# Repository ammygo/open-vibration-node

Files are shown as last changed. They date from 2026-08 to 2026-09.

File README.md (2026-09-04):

# Open Vibration Node

An open hardware and open firmware vibration sensing node for industrial condition
monitoring — analysing vibration **on the device** and reporting results over LoRaWAN to a
gateway you run yourself, with no mandatory cloud service.

> **Status: sensor board verified, radio path not yet exercised.** The second-generation
> sensor board has been manufactured and verified on the bench — the sensor identifies
> correctly, gravity and impact-response tests pass, and the noise floor sits at ~18 mg RMS
> across the full 6.3 kHz bandwidth on a bench ([measurements](docs/measurements.md)). The RAK3112 module has so far served only as the
> host MCU for those tests; the SX1262 radio has not yet been brought up. Mechanical
> integration and the signal-processing firmware are the current work.

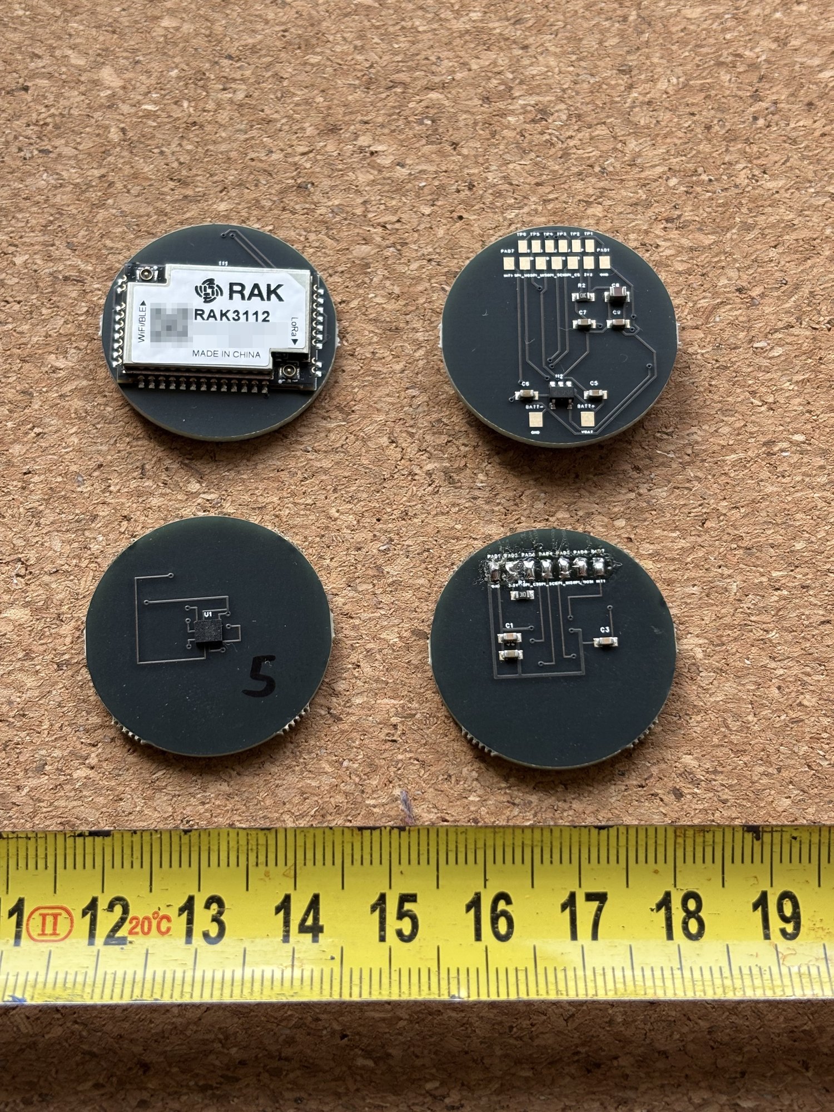
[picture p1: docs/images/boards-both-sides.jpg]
Both boards, both sides, with a ruler for scale


*The two 28 mm boards that make up a node — sensor board and radio board, both sides.
More photographs: [docs/images](docs/images/).*

## Why this project exists

Predictive maintenance works: measuring vibration on motors, bearings, pumps and fans
reveals developing faults weeks or months before they cause a breakdown. The techniques
are well documented in engineering literature, and the sensors cost a few euros.

Access to them is not open, though. Commercial condition-monitoring systems are closed
end to end — proprietary sensors, proprietary gateways, and a vendor cloud that must stay
reachable and paid for, or the equipment stops being monitored. Prices start in the
hundreds of euros per measurement point, which puts continuous monitoring out of reach for
small manufacturers, municipal utilities, water pumping stations and building services —
exactly the operators who can least afford an unplanned failure.

Open vibration-monitoring projects do exist. The ones I have found stop at a development
board on a desk, depend on a vendor cloud, or use accelerometers limited to a few hundred
hertz — which rules out the 1–6 kHz region where bearing faults first appear. What is
missing is a node that combines the bandwidth needed for real diagnostics with local-first
operation and documentation good enough to rebuild it. This project aims to be that node.

## How this compares with existing work

| Approach | Usable bandwidth | Power / connectivity | Openness |
|---|---|---|---|
| Commercial condition-monitoring systems | Full (piezo-based) | Battery or wired; vendor cloud mandatory | Closed end to end; per-point pricing plus subscription |
| Open builds on consumer MEMS (ADXL345 / LIS3DH class) | ~200–800 Hz | Battery; various | Open, but physically blind to the 1–6 kHz bearing-fault region |
| Wired piezo + DAQ setups | Full | Mains power and cabling per point | Mixed; cabling dominates per-point cost |
| **This project** | **DC–6.3 kHz (IIS3DWB)** | **Battery + LoRa; local-first, no mandatory cloud** | **Open: hardware, firmware, docs, production files** |

Open lab-instrument projects — open microscopes, open test equipment — have already shown
that *laboratory-grade but open and rebuildable* is a workable model. This project applies
that model to industrial vibration monitoring.

## Design goals

These are the goals the design is being built towards, not a description of what already
works — see the status above.

- **Analysis on the device.** FFT and envelope processing run on the node's MCU. Only
  results leave the device — a compact payload of dominant frequencies, amplitudes, RMS
  and temperature (target: under 24 bytes), not raw waveforms. This is what makes
  battery-powered operation over a low-bandwidth radio possible at all.
- **Local-first.** LoRaWAN with a self-hosted [ChirpStack](https://www.chirpstack.io/)
  network server: the reference gateway is a Raspberry Pi 5 with an SX1302 eight-channel
  concentrator, and everything from radio to database runs on hardware the operator owns.
  No account, no vendor cloud, no remote kill switch. Cloud services are optional, never
  required.
- **Auditable and reproducible.** Schematics, bill of materials, firmware source and
  enclosure models under free licences, with build documentation detailed enough to
  reproduce a working node.
- **Long field life.** Multi-year operation on a primary lithium cell. Sealed enclosure
  for industrial and outdoor use.
- **Secure by design.** Per-device keys, signed firmware updates and a published software
  bill of materials, so that nodes remain maintainable under the EU Cyber Resilience Act
  rather than becoming unsupported hardware.

## Hardware

| Block | Part | Key figures |
|---|---|---|
| Accelerometer | STMicroelectronics **IIS3DWB** | DC–6.3 kHz flat bandwidth, 26.667 kHz ODR, 75 µg/√Hz noise density, ±2/4/8/16 g, SPI, −40…+105 °C, integrated temperature sensor |
| MCU + radio | RAK Wireless **RAK3112** | ESP32-S3 + Semtech SX1262 in one certified module (LoRa 868 MHz, WiFi, BLE), 23×15 mm |
| Power | Diodes **AP2112K-3.3** LDO | 600 mA, SOT-23-5 (LCSC C51118) |

### Why these parts

**IIS3DWB.** Bearing and mechanical fault signatures live in the 1–6 kHz region, while
ordinary MEMS accelerometers (ADXL345, LIS3DH and similar) are limited to 200–800 Hz —
they physically cannot see what matters. The IIS3DWB gives a flat 6.3 kHz bandwidth at
75 µg/√Hz noise in a single 2.5 × 3.0 mm package, so diagnostics that previously required
a piezoelectric accelerometer with an external conditioner now fit in a 28 mm node running
from a battery.

**RAK3112.** The ESP32-S3 has enough compute to run the FFT locally, which is the whole
premise of the design: the node transmits a spectral summary rather than raw waveforms,
which is what makes both the battery budget and the LoRa duty cycle work. Combining it
with the SX1262 in one certified module means a single component instead of MCU plus radio
plus RF matching, and no antenna network to design. The trade-off is board area in
exchange for reproducibility and a simpler certification path — a deliberate choice for a
project that others are meant to be able to rebuild.

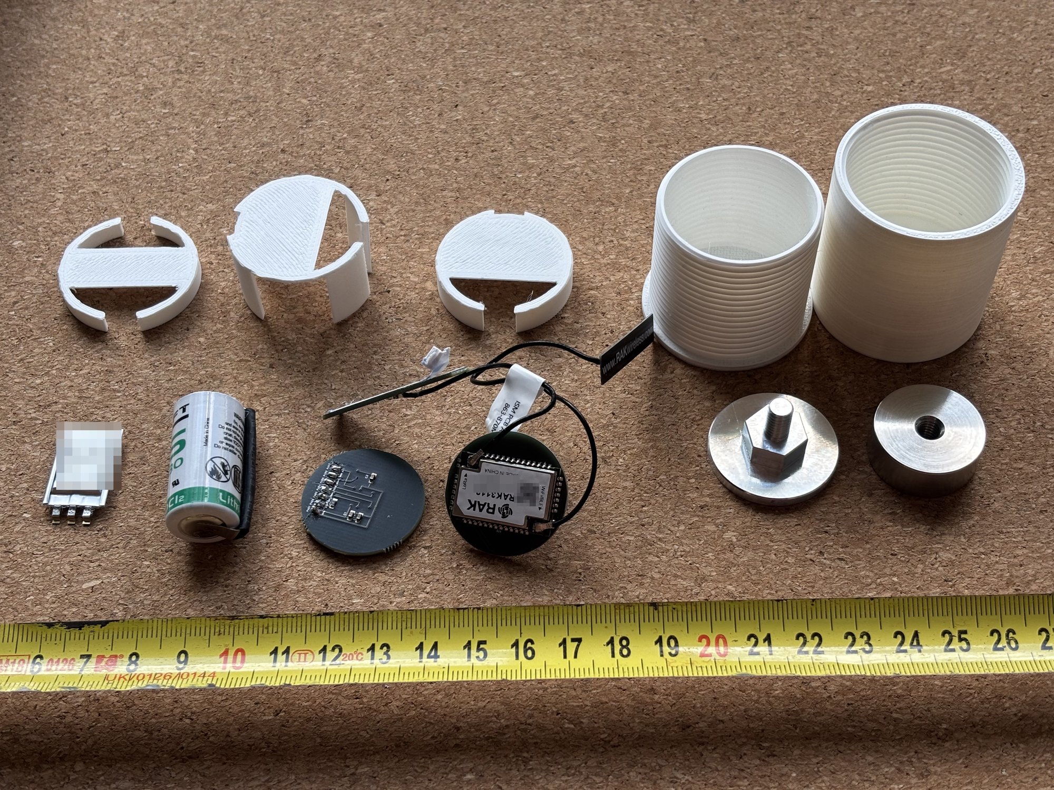
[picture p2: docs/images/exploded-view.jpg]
Every part of a node laid out


*Everything that goes into one node: the two boards, primary cell, energy buffer,
antennas, printed housing and the aluminium mounting pad.*

### Board architecture

Two 28 mm round boards with the battery between them, joined by seven wires:

- **Sensor board** — IIS3DWB on the bottom layer, facing the measured surface, with
  decoupling capacitors and a CS pull-up.
- **Radio board** — RAK3112 on the top layer (antenna facing away from metal), LDO and
  power components underneath.

Inter-board signals: `GND`, `3V3`, `SPI_CS`, `SPI_SCK`, `SPI_MISO`, `SPI_MOSI`, `INT1`.
Pad order is identical on both boards, so the wires run straight across without crossing.

Placing the accelerometer on the bottom layer is deliberate — it shortens the mechanical
path between the measured surface and the sensing element, which matters far more for
signal fidelity than any amount of filtering afterwards.

### Two data paths

A node normally sends only a spectral summary — a payload of a couple of dozen bytes,
which is what makes years of battery life on a low-bandwidth radio possible at all. That
summary is enough to trend a machine's condition, but not to investigate a fault in detail.

So the node keeps a second path. The RAK3112 carries 8 MB of PSRAM, enough to hold about
50 seconds of the full 26.667 kHz three-axis stream. When something in the trend needs
looking at, an engineer standing next to the machine can trigger a capture and pull the
raw recording off over WiFi, straight to a laptop — no cloud and no gateway involved.
This path works on the bench as of September 2026: a downlink command makes the node record
32768 samples per axis (1.23 s — the PSRAM allows about 50 s; 1.23 s is the current capture
length) from the sensor FIFO into PSRAM and post them over WiFi to the collector (the local
server described above; a laptop also works), which it locates by mDNS.

This is deliberately **on demand** rather than continuous: streaming raw data would end the
battery budget within days. Routine monitoring stays cheap; full detail is available when
it is actually needed.

## Repository layout

| Path | Contents |
|---|---|
| `firmware/tests/` | Bench verification sketches — sensor identification and acquisition |
| `docs/` | Measurements, payload specification draft, build notes |
| `enclosure/` | Mounting pad and housing — CAD sources with open-format exports |
| `tools/` | Design-check utilities: a mirrored-footprint checker and the velocity-RMS filter validation script |
| `hardware/` | KiCad boards plus gerbers, BOM and pick-and-place files for both boards |

## Licences

- Firmware and software: [MIT](LICENSE)
- Hardware design files: CERN-OHL-W-2.0 (see `hardware/LICENSE.txt`)
- Documentation: CC-BY-SA-4.0

## Roadmap

Timing is indicative and assumes part-time development; with project funding it compresses.

1. ~~Sensor board validated on hardware~~ — done, August 2026 ([measurements](docs/measurements.md))
2. ~~Radio bring-up: SX1262 transmit and receive path~~ — done, September 2026: point-to-point
   LoRa link (869.525 MHz, SF7) in both directions, downlink-configurable cadence within the
   duty-cycle budget, on-demand raw capture over WiFi; velocity RMS in the ISO 10816 band
   validated ([measurements](docs/measurements.md#velocity-rms-in-the-iso-10816-band-added-2-september-2026)).
   The interim link terminates in a USB LoRa receiver on the collector (the local server
   described under *Local-first*); roadmap item 4 replaces it with the SX1302 LoRaWAN gateway
   and ChirpStack.
3. Mechanical integration: sensor coupling, sealing, field-ready housing (pad and housing
   models [published](enclosure/); sealing details in progress) — winter 2026/27
4. On-device FFT and envelope processing, LoRaWAN uplink with a versioned payload format
   ([draft specification](docs/payload-spec.md)) — spring 2027. *Interim: FFT, envelope and
   waterfall spectra are computed on the collector from FIFO captures; each packet already
   carries band-limited velocity RMS, crest factor and a sensor-health flag
   ([status](docs/payload-spec.md#bench-protocol-status-2-september-2026)).*
5. Characterisation against a reference accelerometer on a shaker — spring/summer 2027
6. Field deployment on real rotating equipment, with published measurement data — second
   half of 2027
7. Documented reproducible build — someone else assembles a node from this repository —
   late 2027

## About

Built by Laurynas Misiūnas, an electronics engineer in Klaipėda district, Lithuania, with
six years of industrial experience deploying edge AI vision systems and embedded
controllers on production lines. Developed with the support of the Klaipėda Science and
Technology Park (KMTP) innovation support programme.

Contributions, review and questions are welcome — see [CONTRIBUTING.md](CONTRIBUTING.md) or open an issue.

## Transparency: use of generative AI

Engineering decisions, architecture and project direction in this repository are made by
the author. Documentation and English-language texts are drafted with the assistance of a
large language model (Anthropic Claude) and reviewed, corrected and approved by the author
before publication. Commits with LLM-assisted content carry a `Co-Authored-By: Claude`
trailer. Details in [TRANSPARENCY.md](TRANSPARENCY.md).

No firmware, hardware design files or measurement data will be presented as project
deliverables without human authorship and verification.

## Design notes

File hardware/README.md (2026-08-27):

# Hardware

Two 28 mm round boards, joined by seven wires with the battery between them.

Licence: CERN-OHL-W-2.0 — see [LICENSE.txt](LICENSE.txt).

| Path | Board | Contents |
|---|---|---|
| `sensor-board/` | IIS3DWB accelerometer, bottom layer | KiCad board, gerbers, BOM, pick-and-place |
| `radio-board/` | RAK3112 module (ESP32-S3 + SX1262), LDO | KiCad board, gerbers, BOM, CPL, pick-and-place |

The `production/` files under each board are the sets actually sent for fabrication and
assembly — not idealised exports. Boards from these files have been manufactured and the
sensor board verified on the bench ([measurements](../docs/measurements.md)).

### What the KiCad sources are and are not

**The gerbers are the authoritative artifact** — they are what was manufactured. The KiCad
files are the design sources behind them, and on both boards they differ from the gerbers
in ways worth knowing before you rebuild:

- **Sensor board** — fully routed, but one CS track and its via sit about 0.1 mm from
  where the manufactured gerbers place them. The final clearance fix was applied in the
  export tool rather than back-annotated to KiCad. Electrically identical; regenerating
  gerbers from KiCad will not produce a byte-identical set.
- **Radio board** — carries **placement and netlist only, with no routing**. The routing
  was done in the export tool and exists solely in the gerbers. Opening this file will
  show an unrouted board; that is the actual state of the source, not a damaged file.

If you intend to modify either design, start from the gerbers for what was built and treat
the KiCad files as the placement reference.

Both boards, both sides

*Sensor board (bottom row) and radio board (top row), both sides. The accelerometer sits
on the underside of the sensor board; the RAK3112 module on the top of the radio board.*

## Inter-board wiring

`GND`, `3V3`, `SPI_CS`, `SPI_SCK`, `SPI_MISO`, `SPI_MOSI`, `INT1`.

Pad order is identical on both boards, so the wires run straight across without crossing.

## Layout constraints worth knowing

Two requirements pull against each other on a 28 mm board, and the layout is the
compromise between them:

- The accelerometer needs a **short, stiff mechanical path** to the mounting surface,
  which is why it sits on the bottom layer facing the measured surface rather than on top.
- The radio needs a **clean ground plane and antenna keep-out**, which is why the module
  sits on the top layer with the antenna facing away from the mounted metal.

Splitting these onto two boards resolves the conflict; the cost is the seven-wire harness
and the assembly step that goes with it.

## Before you reorder these boards

Run [`../tools/check_handedness.py`](../tools/README.md) against the sensor board. A
mirrored bottom-layer footprint passes design rule checking and fabricator review and
still cannot be assembled — that mistake cost three revisions here.

## Bill of materials

The BOM files carry LCSC part numbers where the boards were assembled with them, so the
component selection can be reproduced directly. Prices, suppliers and order references are
deliberately not included.

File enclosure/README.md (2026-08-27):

# Enclosure and mechanical parts

Licence: CERN-OHL-W-2.0 (same terms as `../hardware`); documentation CC-BY-SA-4.0.

| Path | Contents |
|---|---|
| `mounting-pad/` | Threaded pad coupling the sensor board to the machine surface — published |
| `housing/` | Sensor housing, revision 3 — published, sealing details in progress |

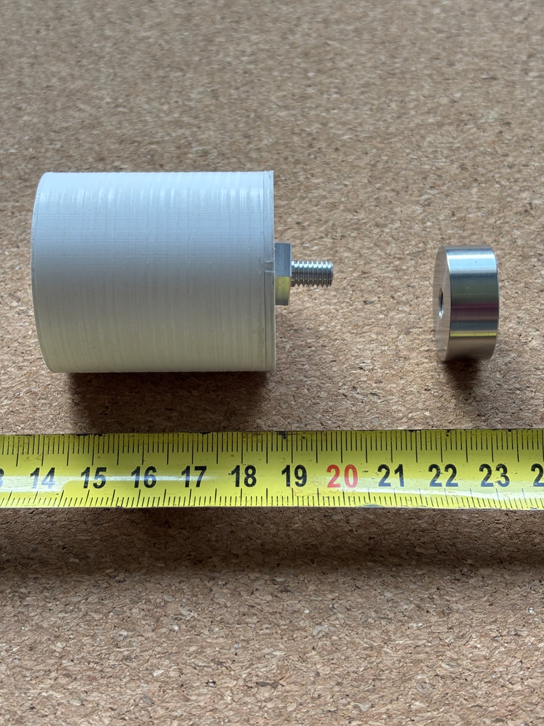
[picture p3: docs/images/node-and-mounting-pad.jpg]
Node alongside the aluminium mounting pad


*The node screws onto the pad by its M6 stud; the pad is turned into the machine housing.
Assembled views: [upright](../docs/images/assembled-node-upright.jpg),
[side](../docs/images/assembled-node-side.jpg),
[opened](../docs/images/housing-open.jpg).*

## Design notes

The enclosure has to do three things at once: transmit vibration faithfully from the
mounting surface to the sensor, keep moisture and dust out, and not shield the antenna.

Planned approach: a stiff mounting path from the pad through the board to the sensor, a
gasket groove for an EPDM or silicone O-ring cord (printed gaskets leak through layer
lines and are not used for sealing), a membrane-vented port to equalise pressure without
admitting water, and a radio-transparent section over the antenna.

Materials: current prototypes are printed in PLA, which is adequate for fit checks on the
bench and nothing more. Field units need ASA for outdoor and UV exposure, or PC/PC-FR where
surface temperatures are high; both require a heated chamber to print without warping, and
printer requirements will be documented alongside the profiles.

Threaded brass inserts are used for all fasteners; printed threads do not survive repeated
opening or vibration.

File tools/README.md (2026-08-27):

# Tools

## `check_handedness.py` — catching mirrored footprints on the bottom layer

A mirrored footprint is one of the few PCB errors that survives every normal check.
Design rule checking passes, the fabricator's review passes, the boards arrive looking
perfect — and the chip cannot be assembled correctly, because no rotation will ever bring
its pins onto the right pads. In this project that mistake killed three board revisions
before it was understood.

This script catches it before the order is placed.

### The rule, in plain language

A chip lying lands-up on a table looks exactly like the datasheet **bottom view**. Lifting
it straight up onto the underside of a board changes nothing about that arrangement.

Therefore: for a bottom-mounted part, the pad positions in world coordinates must match
the datasheet bottom view **up to a single common rotation** — 0°, 90°, 180° or 270°.
If no rotation matches, the footprint is mirrored, and no amount of rotating in the
assembly file will fix it.

Understanding this rule matters more than running the script. The script only automates
the comparison.

### What it does

Reads pad coordinates straight from the KiCad `.kicad_pcb` file, converts them into world
coordinates, and compares them against the datasheet's bottom-view land positions at each
of the four rotations, reporting the worst-case pad error for each.

### Example output

Current sensor board — correct footprint:

```
================================================================
HANDEDNESS CHECK: bottom-v5
   rotation   0 deg: max pad error = 2.9369 mm
   rotation  90 deg: max pad error = 2.0767 mm
   rotation 180 deg: max pad error = 0.0000 mm
   rotation 270 deg: max pad error = 2.0767 mm
   >>> PASS: pads = datasheet BOTTOM VIEW rotated 180 deg
   >>> chip is PLACEABLE; CPL rotation must be 180 deg
```

One rotation lands at zero error — the footprint is correct, and the assembly file must
use that same rotation. On a mirrored footprint all four rotations stay far from zero and
the script reports `FAIL: FOOTPRINT IS MIRRORED`; that is the outcome that would have
saved three board revisions here.

### Usage

```
python check_handedness.py path/to/board.kicad_pcb
```

No dependencies beyond the Python standard library.

### Adapting it to another part

Two things are specific to this project and need editing for a different design:

- `DS_BOTTOM` — the land coordinates read from the datasheet's package drawing. Replace
  with the values for your part.
- The board-origin offsets in the world-coordinate conversion (`- 150.0`, `- 100.0`) —
  set these to your board's origin.

The footprint filter currently selects `LGA-14`; change it to match your package name.

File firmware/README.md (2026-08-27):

# Firmware

Node firmware: sampling, on-device signal processing, power management and LoRaWAN uplink.

Licence: MIT — see [../LICENSE](../LICENSE).

## Contents

Bench sketches are under `tests/`. Still to come:

- `src/` — application and signal processing sources
- `drivers/` — sensor and peripheral drivers
- `docs/` — payload format specification and decoder

## Processing pipeline

```
sample burst  ──►  window  ──►  FFT + envelope  ──►  extract features  ──►  pack payload
(configurable      (Hann)      (band-limited)       (peaks, RMS, temp)     (< 24 bytes)
 rate and length)
```

The node stays asleep between measurements, wakes on schedule or on an RMS threshold,
computes locally and transmits only extracted features. Raw waveforms are never sent over
the radio — they can optionally be stored on local media for offline analysis.

## Payload

The uplink format will be documented as a versioned specification, with a reference
decoder so that any LoRaWAN network server can interpret the data without proprietary
software. Every payload carries a format version byte so that decoders and firmware can
evolve independently.

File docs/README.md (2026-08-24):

# Documentation

Build instructions, measurement methodology and test results.

Licence: CC-BY-SA-4.0.

## Planned contents

- `build/` — step-by-step assembly, from bare PCB to sealed node
- `commissioning/` — mounting guidance, orientation, sampling configuration
- `methodology/` — how measurements are taken and interpreted: baseline capture,
  temperature correction, threshold selection
- `measurements/` — published datasets from bench and field tests, with the raw data

## Why the methodology matters

A vibration reading on its own means nothing. A useful node needs a baseline for the
specific machine, grouped by temperature, and thresholds derived from that baseline rather
than from generic limits. Documenting this properly is as much of the project as the
hardware — it is the part that decides whether an operator gets early warnings or a stream
of false alarms.

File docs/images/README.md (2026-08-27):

# Photographs

Images of the hardware as built, August 2026.

| File | What it shows |
|---|---|
| `boards-both-sides.jpg` | Both boards, both sides, with a ruler for scale |
| `exploded-view.jpg` | Every part of a node laid out: boards, battery, energy buffer, antennas, housing, mounting pad |
| `assembled-node-upright.jpg` | Assembled node standing on its mounting pad |
| `assembled-node-side.jpg` | The same node from the side, showing the pad interface |
| `node-and-mounting-pad.jpg` | Node with its M6 stud alongside the aluminium pad it screws into |
| `housing-open.jpg` | Housing opened, electronics in place |
| `bench-setup.jpg` | Bench setup during acquisition testing |
| `bench-demo-output.jpg` | Serial output of the self-check demo |

## A note on what is obscured

Device identifiers on the radio module and the markings on the energy-buffer capacitor are
pixelated. Everything relevant to rebuilding the node — component choice, layout, wiring,
mechanics — is in the [hardware](../../hardware/) files.

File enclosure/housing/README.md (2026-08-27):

# Sensor housing

Enclosure for the two-board sensor stack, revision 3.

> **Work in progress.** The model is published as it stands, at the stage where the board
> stack and mounting interface are settled but sealing details are still being worked
> through. It is here so the mechanical direction can be reviewed and reused, not because
> it is finished.

## Files

| File | Purpose |
|---|---|
| `src/sensor_housing_v3.f3d` | Fusion 360 source — full editable model |
| `export/sensor_housing_v3.step` | STEP export — opens in any CAD package, no Fusion licence needed |

The STEP export exists deliberately: a design published only in a proprietary format is
not open in any practical sense. Anyone should be able to open, measure and modify this
without a commercial licence.

## Design constraints it has to satisfy

- **Rigid path to the sensor.** The housing must not sit between the mounting pad and the
  sensor board; compliance anywhere in that path attenuates exactly the high-frequency
  content the node exists to measure.
- **Radio transparency.** The RAK3112 antenna faces away from the mounted surface, and no
  metal or carbon-filled material may sit over it.
- **Sealing without printed gaskets.** A groove for EPDM or silicone O-ring cord; printed
  gaskets leak through their layer lines.
- **Pressure equalisation.** A membrane vent, so the enclosure does not pump moisture in
  as it heats and cools outdoors.
- **Serviceable fasteners.** Threaded brass inserts — printed threads do not survive
  repeated opening or sustained vibration.

Licence: CERN-OHL-W-2.0.

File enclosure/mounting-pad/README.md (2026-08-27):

# Mounting pad

A threaded pad that screws into a machine housing and carries the sensor board.

> **Version 1 — known limitation.** This revision has a flat top face and **no pocket for
> the accelerometer**. The IIS3DWB package sits about 0.9 mm below the underside of the
> sensor board, so it will contact a flat pad. A recess of Ø8–10 mm and about 2 mm depth in
> the centre of the top face is required. Existing pads can be drilled by hand; the next
> revision will include the pocket in the source model.

## Dimensions

| Feature | Size |
|---|---|
| Threaded stud | M6 × 1.0, 9 mm long |
| Hex section | 13 mm across flats, 6 mm tall |
| Top platform | Ø30 mm, 3 mm thick |

## Why a pad at all

Vibration measurement is only as good as the mechanical path between the machine surface
and the sensing element. Magnets and adhesive tape introduce compliance that rolls off the
higher frequencies — precisely the 1–6 kHz region where early bearing faults appear. A
threaded pad screwed into the housing gives a stiff, repeatable coupling, and the flat
platform lets the sensor board be bonded across its full area rather than resting on
standoffs.

The hex section exists so the pad can be tightened with an ordinary spanner without
touching the platform surface.

## Files

| File | Purpose |
|---|---|
| `src/mounting_pad_v1.scad` | Parametric source (OpenSCAD) — edit dimensions here |
| `export/mounting_pad_v1.step` | STEP export for CAD work |
| `export/mounting_pad_v1.stl` | Mesh for 3D printing |

The modelled thread is a printable approximation, not a metrological thread form. For
metal pads, cut a real M6 thread; for printed prototypes it holds well enough in a tapped
housing.

Licence: CERN-OHL-W-2.0, as for all hardware in this repository.

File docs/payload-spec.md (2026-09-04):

# Uplink payload specification — DRAFT v0

> **Status: draft for discussion.** The binary format is not transmitted yet; three of its
> elements are already exercised by the interim bench protocol (see
> [Bench protocol status](#bench-protocol-status-2-september-2026)). The format will be
> versioned from the first real transmission, and this document will track it. Review and
> criticism are welcome — open an issue.

## Goals

- Fit comfortably inside LoRaWAN duty-cycle and airtime limits: **24 bytes maximum**, so a
  single uplink carries a complete measurement summary even at slow spreading factors.
- Carry **results, not waveforms**: the node runs FFT and envelope analysis locally and
  transmits a spectral summary. Raw data never has to leave the device.
- Be **self-describing enough to evolve**: an explicit version field, so decoders can
  support mixed fleets.
- Be trivially implementable by third parties: fixed offsets, no compression, integer
  fields with documented scale factors.

## Bench protocol status (2 September 2026)

The binary layout below remains the LoRaWAN target. The bench setup meanwhile runs an
interim point-to-point text protocol (`VIB3 id=… n=… i=… a=… v=… c=… t=… e=…`) so the
collector can be developed against real packets. Three items of this specification are
already exercised there and will carry over unchanged:

- **Sensor-health flag** (the inverse of status bit 0, which is set when the sensor is
  healthy): field `e=` is 1 whenever the accelerometer fails
  identification or does not fill the FIFO. The collector then raises a "sensor fault"
  alarm and suppresses diagnosis instead of reporting a healthy, silent machine.
- **Reboot detection** (what status bits 3 and 5 will carry): for now the collector infers
  a reboot from a sequence number that goes backwards; the node runs a 90 s task watchdog.
- **Airtime budget:** at SF7 / BW 125 kHz / CR 4/7 an 85-byte text packet is 226 ms on
  air. In the 869.4–869.65 MHz sub-band (10 % duty cycle) that caps the cadence at
  ≥ 2.3 s; the node enforces a 3 s minimum (7.5 %). The 24-byte binary format is 86 ms on
  air — one of the reasons it exists. Time on air: `T_sym = 2^SF / BW`,
  `N_payload = 8 + max(ceil((8·PL − 4·SF + 28 + 16) / (4·SF)) · (CR + 4), 0)`,
  `T = (12.25 + N_payload) · T_sym` for an 8-symbol preamble with explicit header and CRC
  (see [measurements, Errata 3](measurements.md#errata-3-bench-cadence-exceeded-the-duty-cycle-limit)).
- **LoRaWAN target:** EU868 uplink channels sit in 1 % sub-bands, and a LoRaWAN frame adds
  13 bytes of MAC header and MIC to the payload. A 24-byte payload (37-byte frame) at SF7
  with CR 4/5 is 82 ms on air, which allows an uplink roughly every 8 s; at SF12 it is
  2.0 s on air, one uplink every ~3.3 minutes. That budget — not the bench link — is what
  sets the summary cadence design. The 10 % sub-band used by the bench link at
  869.525 MHz is reserved in LoRaWAN for RX2 downlinks.

## Proposed layout (19 of 24 bytes used)

| Offset | Size | Field | Encoding |
|---|---|---|---|
| 0 | 1 | Version + message type | high nibble: protocol version (0); low nibble: type (0 = periodic summary) |
| 1 | 1 | Sequence number | uint8, wraps at 255 |
| 2–3 | 2 | RMS acceleration | uint16, 0.1 mg units (0 – 6553.5 mg) |
| 4–5 | 2 | Peak acceleration | uint16, 0.25 mg units (0 – 16383.75 mg — covers the full ±8 g range) |
| 6–8 | 3 | Spectral peak 1 | frequency uint16 (Hz) + amplitude uint8 (0.5 dB steps re 0.1 mg) |
| 9–11 | 3 | Spectral peak 2 | same encoding |
| 12–14 | 3 | Spectral peak 3 | same encoding |
| 15–16 | 2 | Die temperature | int16, 0.1 °C units |
| 17 | 1 | Battery voltage | uint8, 20 mV steps from 2.0 V (covers 2.00 – 7.10 V) — *requires a battery sense divider, planned for the next board revision; current boards route BATT+ to the LDO only* |
| 18 | 1 | Status flags | bitfield, see below |
| 19–23 | 5 | Reserved | zero-filled; candidates: ISO-style band energies, event counters |

### Status flags

| Bit | Meaning |
|---|---|
| 0 | Sensor identified (`WHO_AM_I` = 0x7B this cycle) |
| 1 | Configuration read-back matched what was written |
| 2 | Clipping detected in the analysis window |
| 3 | Watchdog reset occurred since previous uplink |
| 4 | Battery below warning threshold |
| 5 | First uplink after boot |
| 6–7 | Reserved |

Bits 0 and 1 exist because of a lesson this project already paid for: the sensor once ran
at 105 Hz while the code believed 26.667 kHz ([errata](measurements.md#errata-sensor-was-running-at-the-wrong-rate)).
A node should assert its own configuration in every message it sends.

## Scale-factor rationale

- RMS at 0.1 mg per uint16 tops out at 6553.5 mg — above the physical RMS ceiling of a
  ±8 g sensor (8000/√2 ≈ 5657 mg), so the field cannot overflow, while still resolving
  the ~18 mg bench noise floor with margin.
- Peak uses a coarser 0.25 mg step because a peak *can* reach the full ±8 g (8000 mg);
  a 0.1 mg step in a uint16 would clip at 6553.5 mg on hard impacts. The clipping flag
  (bit 2) then indicates true sensor saturation, not encoding overflow.
- Spectral amplitude is referenced to **0.1 mg**, not 1 mg: early bearing defects on a
  quiet machine sit at 0.3–1 mg, and the per-bin noise floor at 13 Hz bins is
  75 µg/√Hz × √13 ≈ 0.27 mg — an unsigned dB value re 1 mg could not represent any of
  that. Re 0.1 mg, one byte at 0.5 dB steps spans 0.1 mg to well beyond sensor range.
- Frequency as plain uint16 Hz covers the DC–6.3 kHz analysis band without a lookup table.

## Acquisition requirement for spectral fields

Spectral peak frequencies are only meaningful if samples are taken at strictly uniform
26.667 kHz intervals. Polled register reads measured on the current firmware reach
14–17 kS/s — sufficient for RMS statistics, **not** for FFT. Acquisition for the spectral
fields must therefore use the sensor's 3 KB FIFO with burst reads, which guarantees
uniform sampling regardless of host timing. The reference firmware will treat this as a
hard requirement.

## Open questions

1. FFT length (2048 vs 4096 points at 26.667 kHz → 13 Hz vs 6.5 Hz bins) — trade between
   frequency resolution, RAM and energy per window.
2. Fixed spectral peaks vs ISO 10816-style band energies in the reserved bytes — peaks
   localise faults, bands trend severity; possibly both.
3. Downlink: configuration channel format (measurement interval, scale, band definitions).
4. Whether application-layer integrity is needed on top of the LoRaWAN MIC, for
   deployments where the network server is not under the operator's control.

## Reference decoder

A reference decoder (Python, single file, no dependencies) will be published alongside the
first implementing firmware, with test vectors.

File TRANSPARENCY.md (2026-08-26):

# Generative AI transparency

This project follows the spirit of the
[NLnet policy on the use of generative AI](https://nlnet.nl/foundation/policies/generativeAI/):
use is permitted, but it must be disclosed and traceable.

## How generative AI is used here

| Area | LLM involvement | Human role |
|---|---|---|
| Documentation, README, English texts | Drafted with Anthropic Claude | Author reviews, corrects and approves every text before it is committed |
| Engineering decisions, architecture, component selection | None — decisions are the author's | Author |
| Firmware and hardware design files | Authored by the author; any LLM-assisted code will be marked in commit messages | Author designs, implements and tests |
| Measurement data and test results | Never generated — only real measurements are published | Author |

## Traceability

- Commits containing LLM-assisted content carry a `Co-Authored-By: Claude` trailer.
- Model used to date: Anthropic Claude (2026). Prompt logs for grant applications are
  maintained separately and disclosed to funders as required by their policies.

## Contact

Questions about any specific content's provenance: open an issue.

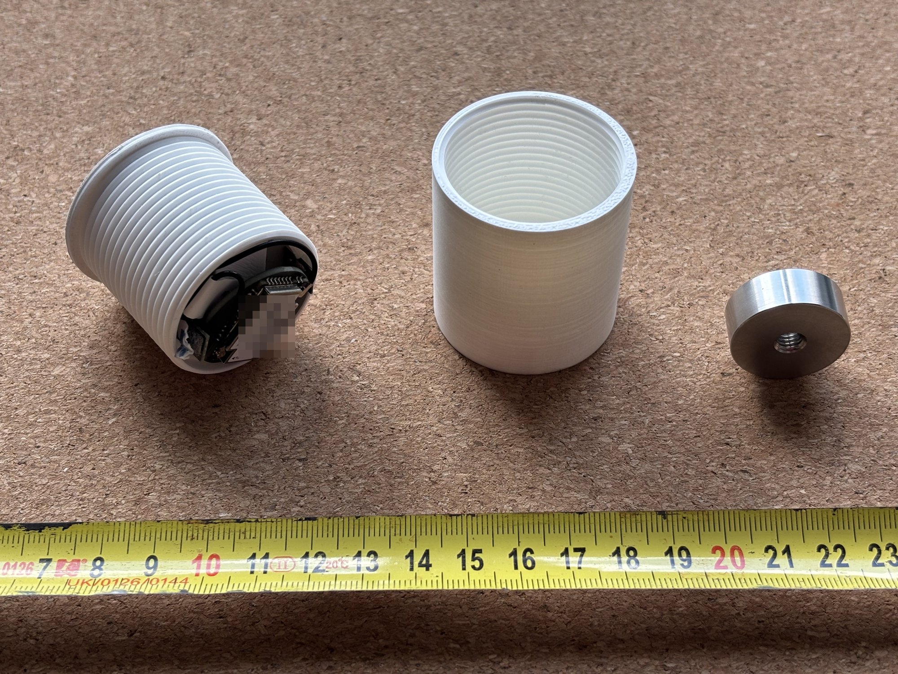
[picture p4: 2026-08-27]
docs/images/housing-open.jpg

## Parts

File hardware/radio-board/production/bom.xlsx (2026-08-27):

Comment | Designator | Footprint | LCSC Part # | Note
RAK3112 | U1 | RAK3112 (23x15 IPEX, 4-sided castellated) | C51883856 | CONFIRM in JLCPCB 'Confirm Parts': stock + that it is the RAK3112 IPEX (u.FL) variant. Check pin-1 / rotation in 3D preview.
AP2112K-3.3 | U2 | SOT-23-5 | C51118 | 3.3V 600mA LDO. Check pin-1 (IN) / rotation in 3D preview.
1uF | C5,C6,C7 | C0603 | C15849 | 1uF 0603 (non-polar)
10uF | C8 | C0805 | C15850 | 10uF 0805 (non-polar)
100nF | C9 | C0603 | C14663 | 100nF 0603 (non-polar)
10k | R2 | C0603 | C25804 | 10k 0603

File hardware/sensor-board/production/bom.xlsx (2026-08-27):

No. | Quantity | Comment | Designator | Footprint | Value | Manufacturer Part | Manufacturer | Supplier Part | Supplier
1 | 2 | 100nF | C1,C3 | Capacitor_SMD:C_0603_1608Metric
2 | 1 | 1uF | C2 | Capacitor_SMD:C_0603_1608Metric
3 | 1 | GND | PAD1 | Connector_PinHeader_2.00mm:PinHeader_1x01_P2.00mm_Vertical
4 | 1 | 3.3V | PAD2 | Connector_PinHeader_2.00mm:PinHeader_1x01_P2.00mm_Vertical
5 | 1 | SPI_CS | PAD3 | Connector_PinHeader_2.00mm:PinHeader_1x01_P2.00mm_Vertical
6 | 1 | SPI_SCK | PAD4 | Connector_PinHeader_2.00mm:PinHeader_1x01_P2.00mm_Vertical
7 | 1 | SPI_MISO | PAD5 | Connector_PinHeader_2.00mm:PinHeader_1x01_P2.00mm_Vertical
8 | 1 | SPI_MOSI | PAD6 | Connector_PinHeader_2.00mm:PinHeader_1x01_P2.00mm_Vertical
9 | 1 | INT1 | PAD7 | Connector_PinHeader_2.00mm:PinHeader_1x01_P2.00mm_Vertical
10 | 1 | 10k | R1 | Resistor_SMD:R_0603_1608Metric
11 | 1 | IIS3DWB | U1 | Package_LGA:LGA-14_3x2.5mm_P0.5mm

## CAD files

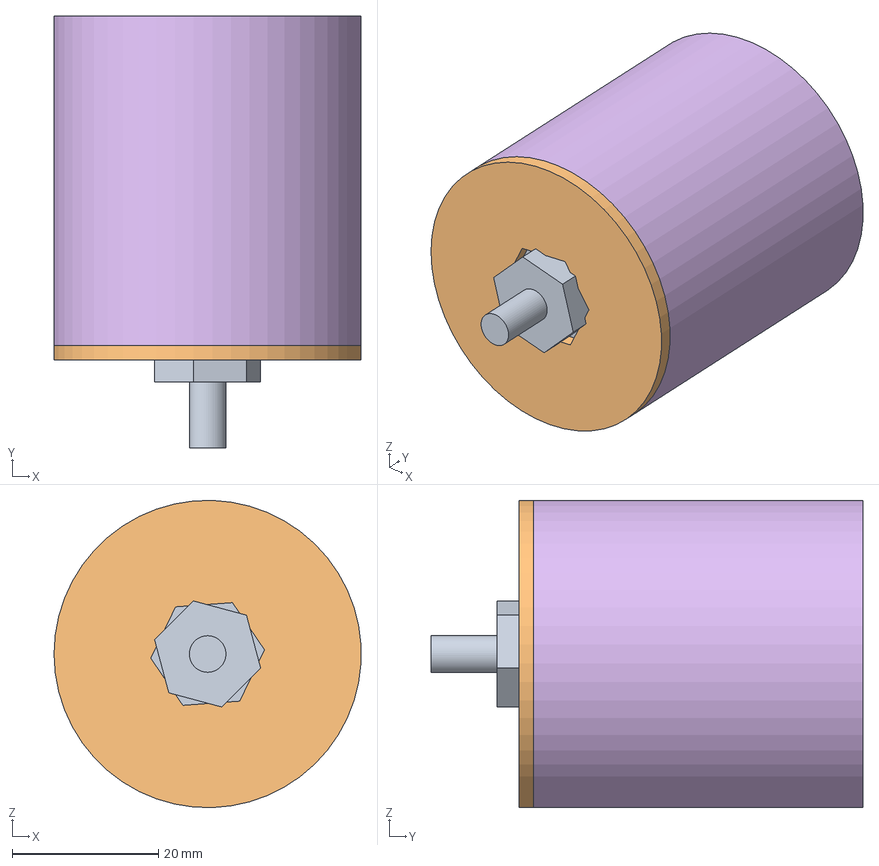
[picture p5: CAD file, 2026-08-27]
enclosure/housing/export/sensor_housing_v3.step
42.0 x 59.0 x 42.0 mm

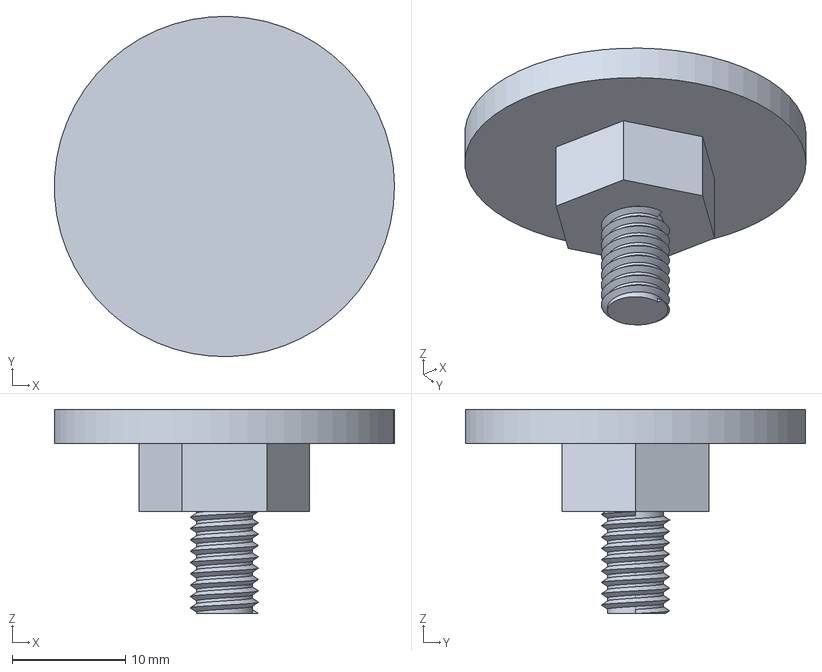
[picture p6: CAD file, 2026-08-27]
enclosure/mounting-pad/export/mounting_pad_v1.step
30.0 x 30.0 x 18.0 mm

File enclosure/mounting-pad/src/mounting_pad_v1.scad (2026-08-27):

// Mounting Pad for Vibration Sensor with physical M6 Thread
$fn = 64;

top_plate_diameter = 30.0;
top_plate_thickness = 3.0;

hex_across_flats = 13.0;
hex_thickness = 6.0;

stud_diameter = 6.0; 
stud_length = 9.0;

module hexagon(flat_to_flat, height) {
    r = (flat_to_flat / 2.0) / cos(30);
    cylinder(r = r, h = height, $fn = 6);
}

// Helical thread module for OpenSCAD (useful for 3D printing)
module helical_thread(dia, pitch, length) {
    r_major = dia / 2.0;
    r_minor = r_major - 0.613 * pitch; // standard metric thread depth
    turns = length / pitch;
    steps_per_turn = 32;
    total_steps = turns * steps_per_turn;
    
    // We construct the thread by stacking small slices or cylinders
    // For a simple visual representation in OpenSCAD, we stack thin layers:
    for (i = [0 : total_steps - 1]) {
        z1 = -length + (i / total_steps) * length;
        z2 = -length + ((i + 1) / total_steps) * length;
        
        // Vary radius to simulate a thread profile
        angle = 360.0 * i / steps_per_turn;
        // Simple triangular thread approximation
        factor = 0.5 + 0.5 * sin(angle);
        r1 = r_minor + (r_major - r_minor) * factor;
        
        angle2 = 360.0 * (i + 1) / steps_per_turn;
        factor2 = 0.5 + 0.5 * sin(angle2);
        r2 = r_minor + (r_major - r_minor) * factor2;
        
        translate([0, 0, z1])
            cylinder(r1 = r1, r2 = r2, h = (z2 - z1), $fn = 24);
    }
}

union() {
    // 1. Physical M6 Threaded Stud (Pitch = 1.0mm)
    helical_thread(stud_diameter, 1.0, stud_length);
    
    // 2. Hexagon section
    hexagon(hex_across_flats, hex_thickness);
        
    // 3. Top flat plate
    translate([0, 0, hex_thickness])
        cylinder(d = top_plate_diameter, h = top_plate_thickness);
}

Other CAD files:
enclosure/housing/src/sensor_housing_v3.f3d
enclosure/mounting-pad/export/mounting_pad_v1.stl

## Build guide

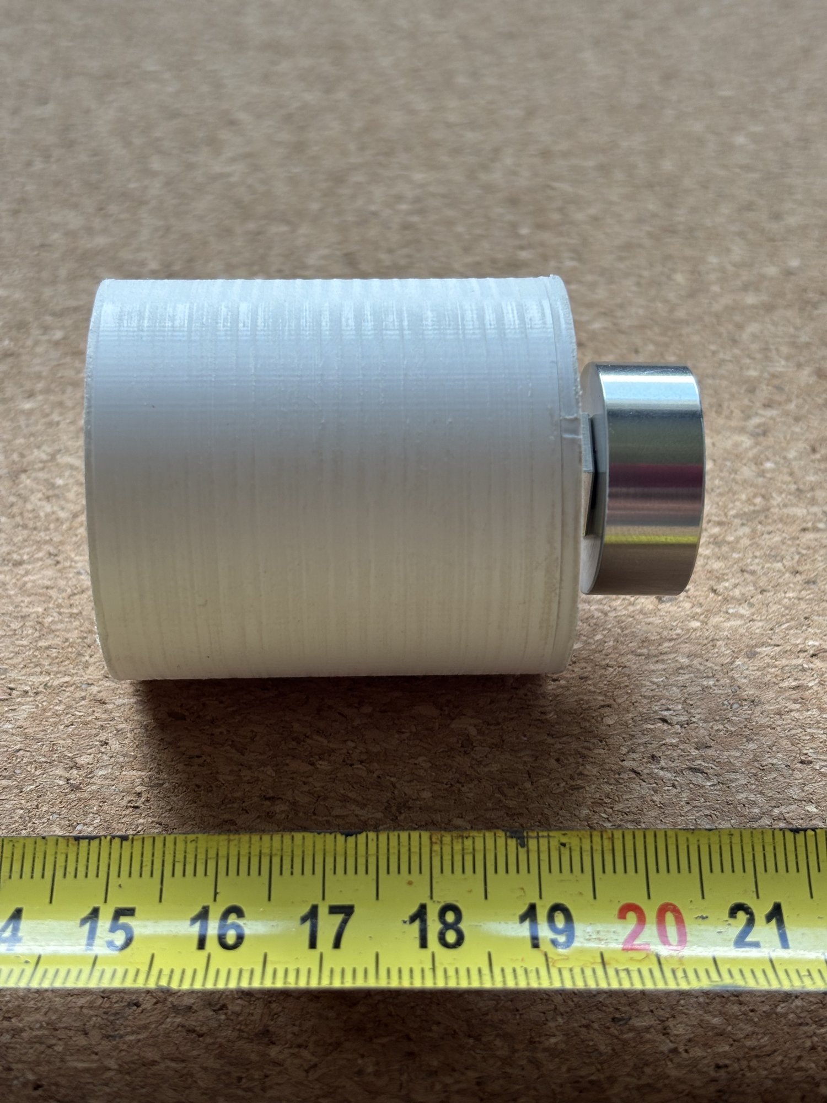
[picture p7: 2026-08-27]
docs/images/assembled-node-side.jpg

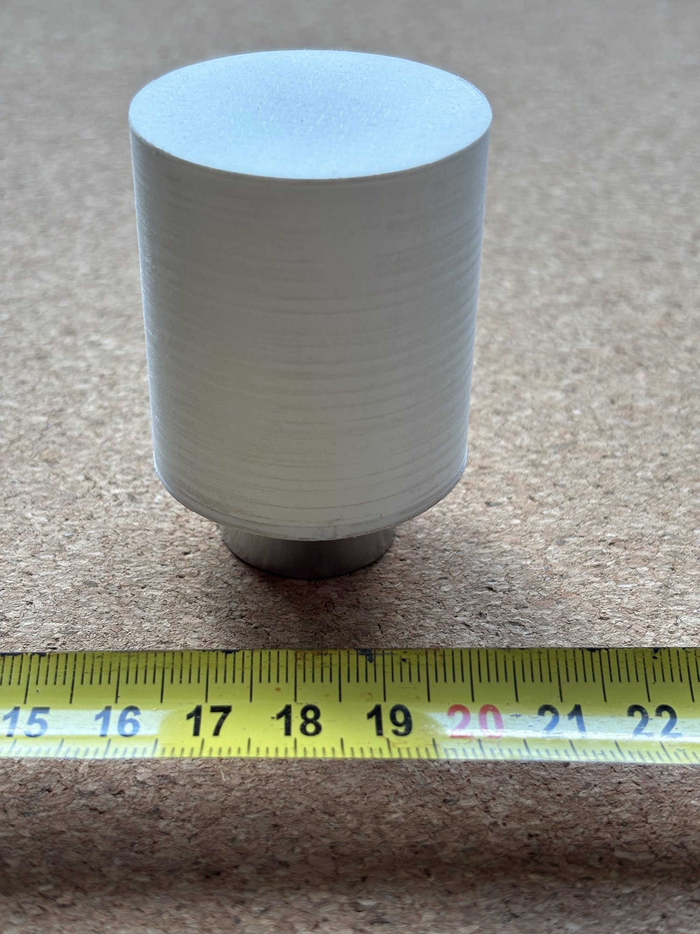
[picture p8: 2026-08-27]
docs/images/assembled-node-upright.jpg

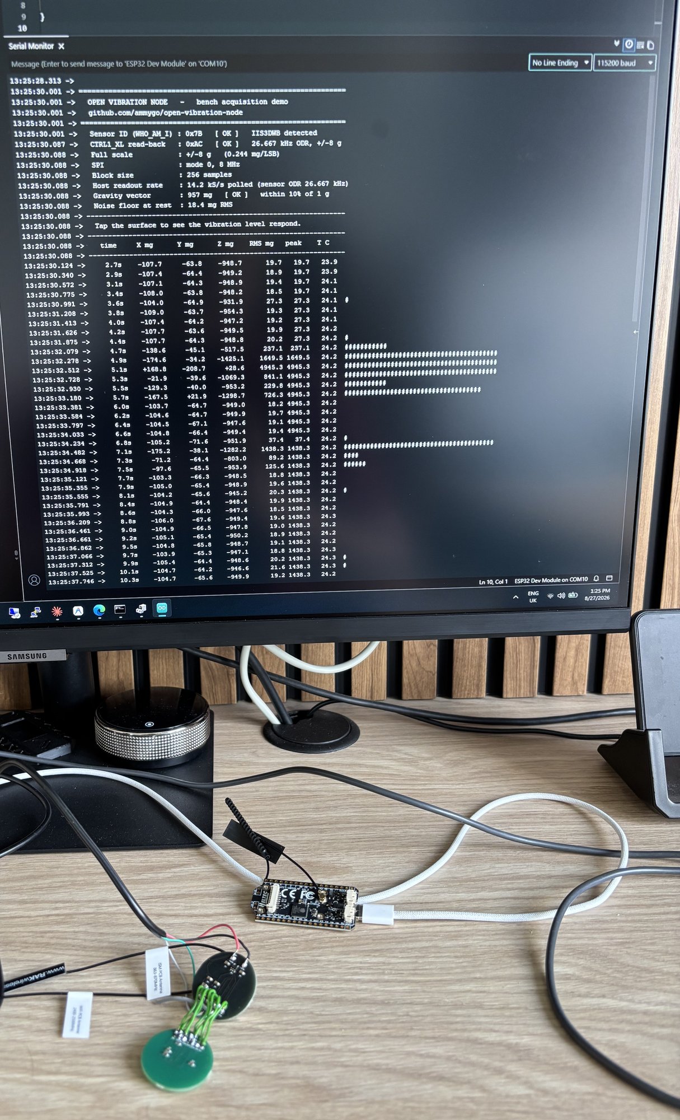
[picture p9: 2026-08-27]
docs/images/bench-setup.jpg

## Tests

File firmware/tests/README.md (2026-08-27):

# Bench tests

Minimal Arduino sketches used to bring up and verify the sensor board. They are
deliberately simple — no filtering, no thresholds, no interpretation — so that anyone
rebuilding this hardware can confirm the basics work before adding anything on top.

| Sketch | Purpose |
|---|---|
| `sensor_id/` | Reads `WHO_AM_I` in SPI Mode 0 and Mode 3, and checks whether MISO floats. Use this first when a board does not respond. |
| `acquisition/` | Configures the IIS3DWB (26.667 kHz ODR, ±8 g, BDU), reads 256-sample windows and prints mean, RMS and die temperature over serial. |
| `bench_demo/` | Full self-check sequence: identity, configuration read-back, gravity vector and noise floor, printed as a readable report. |

Wiring as used on the current boards: `SCK` 13, `MISO` 10, `MOSI` 11, `CS` 12.
Expected `WHO_AM_I` value is `0x7B`. The part responds in SPI Mode 0 only.

`CTRL1_XL` must be written as `0xAC` for 26.667 kHz at ±8 g. The value `0x2C` is an
undocumented combination that the part accepts while running at roughly 105 Hz — it cost
us a published measurement before it was caught, so these sketches now read the register
back and report what the part is actually doing. See the
[errata](../../docs/measurements.md#errata-sensor-was-running-at-the-wrong-rate).

Results from these sketches: [`../../docs/measurements.md`](../../docs/measurements.md).

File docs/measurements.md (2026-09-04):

# Bench measurements

Characterisation of the second-generation sensor board. Configuration: IIS3DWB at
26.667 kHz ODR, ±8 g range, 256-sample windows, SPI Mode 0.

These are **characterisation** results — they describe how the hardware behaves, not how
faults are diagnosed. A shaker comparison against a reference accelerometer is still to be
done.

> **Correction, 28 August 2026.** The noise floor originally published here (~1 mg RMS)
> was measured with a misconfigured sensor and has been replaced. See
> [Errata](#errata-sensor-was-running-at-the-wrong-rate) below — the story of how the
> error surfaced is worth more than the number itself.

## Results

| Measurement | Result |
|---|---|
| Sensor identification (`WHO_AM_I`) | `0x7B`, stable across 7/7 read cycles |
| SPI mode | Mode 0 only; Mode 3 returns `0x00` — the part does not respond in Mode 3 |
| Noise floor at rest, full bandwidth | **~18 mg RMS** (256-sample window, bench surface) |
| Gravity, face down | Z ≈ −957 mg |
| Gravity, inverted | Z ≈ +1018 mg |
| Impact response (tap test) | RMS rises from the noise floor to 77 / 155 / 412 / 900 mg depending on strength |
| Settling after impact | Returns to noise floor in under 1 s |
| On-die temperature | Stable, 26.5–26.9 °C |

Gravity, orientation, identification and settling behaviour are unaffected by the
correction below. The tap-test amplitudes were recorded during initial bring-up and
demonstrate dynamic range and settling rather than absolute amplitude at full bandwidth.

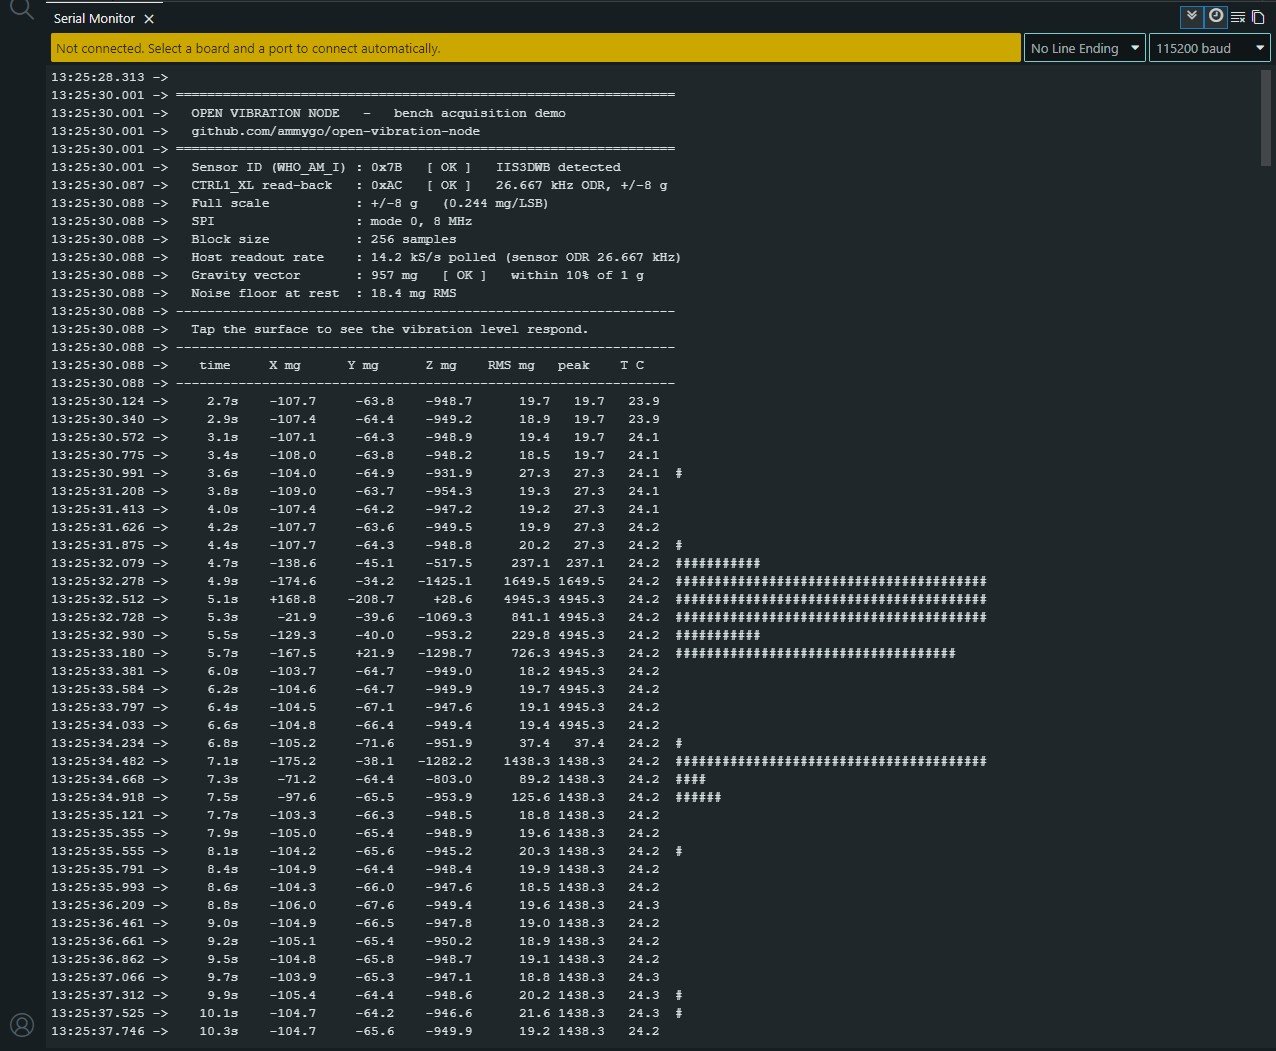
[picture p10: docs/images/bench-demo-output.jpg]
Serial output of the self-check demo


*The `bench_demo` sketch reporting identity, configuration read-back, gravity vector and
noise floor, followed by live samples — the spikes are taps on the bench surface.*

## What these numbers mean

The sign of the gravity reading flips correctly when the board is inverted and the
magnitude sits close to 1 g in both orientations, which confirms axis orientation and
scale factor.

The ~18 mg RMS noise floor is measured across the full 6.3 kHz bandwidth on an ordinary
bench. For reference, the datasheet noise density of 75 µg/√Hz over that bandwidth gives a
theoretical floor of about 5.9 mg for the sensor alone; the difference is the environment —
building vibration reaching the bench, and microphonics in the flying-lead harness between
the two boards. Reducing it is a mechanical and wiring problem, not a sensor problem, and
it is one of the things the enclosure work has to address.

The practical consequence: at full bandwidth on this setup, vibration below roughly 18 mg
RMS is not distinguishable from the background. Narrowing the analysis band — which is what
the FFT does — recovers sensitivity within the bands of interest.

The tap test spans nearly three orders of magnitude without saturating and settles back
within a second, showing the acquisition chain has usable dynamic range and no ringing
that would smear later spectral analysis.

## Velocity RMS in the ISO 10816 band (added 2 September 2026)

The node now reports vibration velocity RMS the way ISO 10816 / ISO 20816 define it:
band-limited to 10–1000 Hz and computed on a gap-free 307 ms window (8192 samples at
26.667 kHz) read from the sensor's hardware FIFO.

Processing chain per axis: remove mean → 2nd-order Butterworth high-pass 8 Hz →
trapezoidal integration to velocity → 2nd-order high-pass 8 Hz (removes integration
drift) → 2nd-order low-pass 1000 Hz → RMS over the last 5462 samples (the first 2730 are
discarded for filter settling). Two cascaded 8 Hz sections give a combined −3 dB point at
10 Hz. The filters run in double precision: at fc/fs ≈ 3·10⁻⁴ a single-precision biquad
loses its poles to rounding.

Validation of the chain against synthetic signals (100 mg amplitude; exact velocity RMS =
a / (2πf·√2)), reproducible with [`tools/vrms_filter_check.py`](../tools/vrms_filter_check.py):

| Signal | Expected | From the chain | Error |
|---|---|---|---|
| 10 Hz (band edge, −3 dB) | 7.80 mm/s | 7.90 mm/s | +1.2 % |
| 24.7 Hz (1480 rpm shaft rate) | 4.47 mm/s | 4.40 mm/s | −1.6 % |
| 50 Hz | 2.21 mm/s | 2.19 mm/s | −0.6 % |
| 100 Hz | 1.10 mm/s | 1.10 mm/s | +0.1 % |
| 500 Hz | 0.221 mm/s | 0.214 mm/s | −3.1 % ¹ |
| 1000 Hz (band edge, −3 dB) | 0.078 mm/s | 0.078 mm/s | −0.4 % |
| 2 Hz, out of band (55 mm/s unfiltered) | — | 0.49 mm/s | rejected 110× |
| 1000 mg DC offset + 24.7 Hz at 50 mg | 2.23 mm/s | 2.20 mm/s | −1.6 % |

¹ Expected, not an error: at half its corner frequency the second-order 1000 Hz low-pass
already attenuates by |H| = 1/√(1 + 0.5⁴) = 0.970.

At rest on the bench the node reports 0.03–0.09 mm/s per axis: the 18 mg wideband noise
floor collapses once the band is limited. The 8192-sample acquisition takes 306 ms
(8192 / 26 667 Hz = 307 ms) — that timing is the permanent check that no samples were
dropped; see the second erratum.

## Errata: sensor was running at the wrong rate

The first published noise floor was ~1 mg RMS. That figure was real in the sense that the
instrument reported it — but it was impossible. With 75 µg/√Hz across 6.3 kHz, no
configuration of this part can produce 1 mg RMS; the arithmetic alone puts the floor near
5.9 mg.

What had happened: the configuration register `CTRL1_XL` was being written as `0x2C`, an
undocumented bit combination. The part accepted it and ran at roughly 105 Hz instead of
26.667 kHz. A 105 Hz bandwidth genuinely does produce a ~1 mg floor — the measurement was
correct for a sensor doing something other than what the code claimed.

The error surfaced from timing, not from reading the datasheet again: sample blocks were
taking far longer to fill than 26.667 kHz would allow. A diagnostic sketch that measured
actual sample rate against register contents confirmed it — `0x2C` gave 105 Hz, `0xAC`
gave full rate, and reading the register back returned what was written.

The correct value is `0xAC`: `XL_EN[2:0] = 101` in bits 7:5, the only permitted setting for
26.667 kHz, with ±8 g in bits 3:2. The bit layout is documented in ST application note
AN5444 rather than the main datasheet register map, which is how the wrong value survived
review in the first place.

Two things worth taking from this. First, always verify the configuration you believe you
wrote — read the register back and check the resulting sample rate, which the sketches
here now do. Second, a measurement that looks better than physics allows is a bug report,
not a result.

## Errata 2: polled acquisition was dropping samples

Until version 6 of the node firmware the per-packet metrics were computed from samples
read one at a time by polling the data-ready flag over SPI. That loop sustains only about
15 kS/s, so roughly 40 % of the 26.667 kHz samples were silently skipped — while the
integration step still assumed 37.5 µs between samples. The FFT path was never affected
(it used the FIFO from the start), but the trended velocity RMS was biased.

It surfaced during a systems audit, not from a wrong-looking number: the time to fill a
block did not match sample count ÷ rate. Everything time-domain now comes from the FIFO,
and the firmware prints the block acquisition time on every cycle so the check cannot be
forgotten. The lesson generalises the first erratum: verify the rate you *achieved*, not
only the rate you configured.

## Errata 3: bench cadence exceeded the duty-cycle limit

For two days of bench testing the node transmitted every 2 s. An 85-byte packet at
SF7 / BW 125 kHz / CR 4/7 is 226 ms on air, so that cadence occupied 11 % of the channel —
above the 10 % permitted in the 869.4–869.65 MHz sub-band. Nothing flagged it: the radio
does not refuse to transmit, and the receiver was a bench unit a metre away at 10 dBm.

It was caught in the systems audit by computing time-on-air from the LoRa symbol formula
instead of estimating it. The node, its downlink configuration path and the collector now
all enforce a 3 s minimum (7.5 %), and the [payload specification](payload-spec.md#bench-protocol-status-2-september-2026)
records the airtime budget so the limit is designed in rather than checked afterwards. The
24-byte binary format planned for LoRaWAN is 86 ms on air — 4.3 % even at 2 s.

## Not yet measured

- Frequency response against a shaker with a calibrated reference accelerometer
- Behaviour across the full −40…+105 °C range
- Long-term drift
- Power consumption in duty-cycled operation

## Reproducing

The sketches under [`../firmware/tests/`](../firmware/tests/) produce these readings:
`sensor_id` verifies the SPI link and part identity, `acquisition` streams mean, RMS and
temperature, and `bench_demo` runs the full self-check sequence including the register
read-back described above. The velocity-RMS filter chain and its validation table are
reproduced by `tools/vrms_filter_check.py` (plain Python, no hardware needed).

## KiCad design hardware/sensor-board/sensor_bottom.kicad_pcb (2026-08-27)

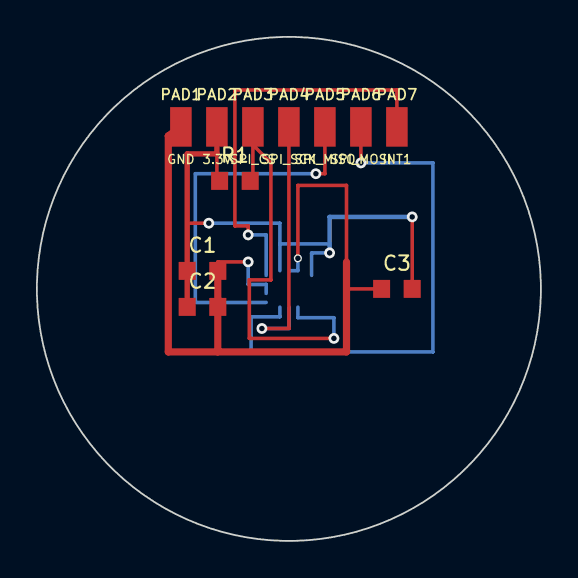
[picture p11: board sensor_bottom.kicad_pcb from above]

Board: 2 copper layers, 28.0 x 28.0 mm, 12 parts (1 on the bottom side), 7 nets.

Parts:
C1, C3: 100nF; C_0603_1608Metric
C2: 1uF; C_0603_1608Metric
PAD1: GND; PinHeader_1x01_P2.00mm_Vertical
PAD2: 3.3V; PinHeader_1x01_P2.00mm_Vertical
PAD3: SPI_CS; PinHeader_1x01_P2.00mm_Vertical
PAD4: SPI_SCK; PinHeader_1x01_P2.00mm_Vertical
PAD5: SPI_MISO; PinHeader_1x01_P2.00mm_Vertical
PAD6: SPI_MOSI; PinHeader_1x01_P2.00mm_Vertical
PAD7: INT1; PinHeader_1x01_P2.00mm_Vertical
R1: 10k; R_0603_1608Metric
U1: IIS3DWB; LGA-14_3x2.5mm_P0.5mm

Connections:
3.3V: C1.1, C2.1, C3.2, PAD2.2, R1.1, U1.5, U1.8
GND: C1.2, C2.2, C3.1, PAD1.1, U1.2, U1.3, U1.6, U1.7
INT1: PAD7.7, U1.4
SPI_CS: PAD3.3, R1.2, U1.12
SPI_MISO: PAD5.5, U1.1
SPI_MOSI: PAD6.6, U1.14
SPI_SCK: PAD4.4, U1.13

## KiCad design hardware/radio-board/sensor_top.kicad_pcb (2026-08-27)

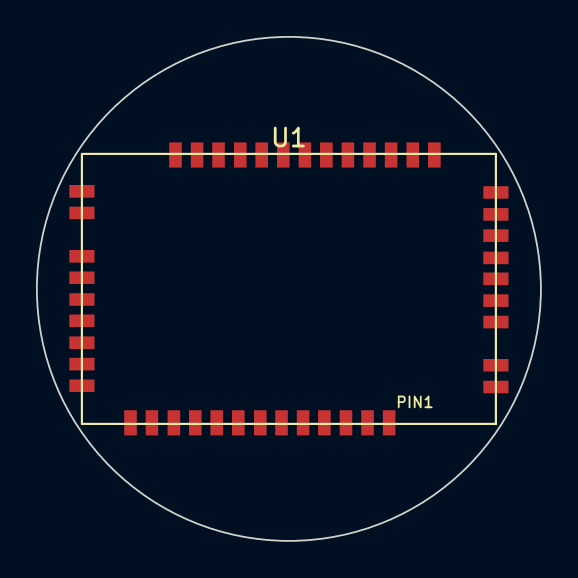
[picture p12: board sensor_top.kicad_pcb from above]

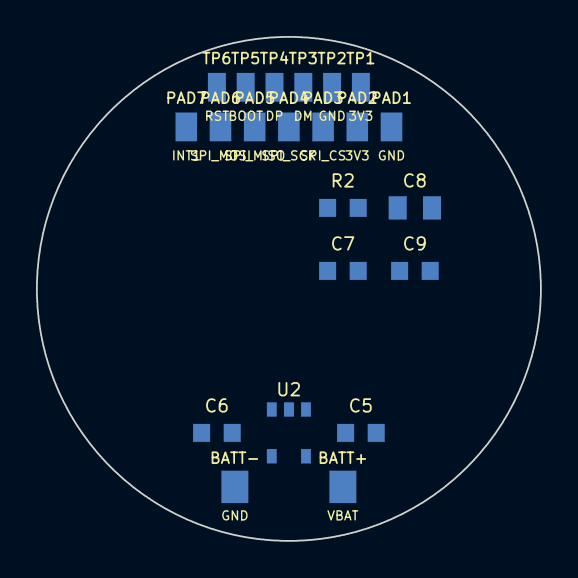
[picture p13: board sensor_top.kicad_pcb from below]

Board: 2 copper layers, 28.0 x 28.0 mm, 23 parts (22 on the bottom side), 12 nets, no tracks yet.

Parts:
BATT+: VBAT; PinHeader_1x01_P2.54mm_Vertical
BATT-: GND; PinHeader_1x01_P2.54mm_Vertical
C5, C6, C7: 1uF; C_0603_1608Metric
C8: 10uF; C_0805_2012Metric
C9: 100nF; C_0603_1608Metric
PAD1: GND; PinHeader_1x01_P2.00mm_Vertical
PAD2: 3V3; PinHeader_1x01_P2.00mm_Vertical
PAD3: SPI_CS; PinHeader_1x01_P2.00mm_Vertical
PAD4: SPI_SCK; PinHeader_1x01_P2.00mm_Vertical
PAD5: SPI_MISO; PinHeader_1x01_P2.00mm_Vertical
PAD6: SPI_MOSI; PinHeader_1x01_P2.00mm_Vertical
PAD7: INT1; PinHeader_1x01_P2.00mm_Vertical
R2: 10k; R_0603_1608Metric
TP1: 3V3; PinHeader_1x01_P2.00mm_Vertical
TP2: GND; PinHeader_1x01_P2.00mm_Vertical
TP3: DM; PinHeader_1x01_P2.00mm_Vertical
TP4: DP; PinHeader_1x01_P2.00mm_Vertical
TP5: BOOT; PinHeader_1x01_P2.00mm_Vertical
TP6: RST; PinHeader_1x01_P2.00mm_Vertical
U1: RAK3112
U2: AP2112K-3.3; SOT-23-5

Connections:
3V3: C6.1, C8.1, C9.1, PAD2.1, R2.1, TP1.1, U1.20, U1.21, U2.5
BOOT: TP5.1, U1.24
GND: BATT-.1, C5.2, C6.2, C7.2, C8.2, C9.2, PAD1.1, TP2.1, U1.14, U1.16, U1.22, U1.35, U1.36, U1.38, U1.42, U2.2
INT1: PAD7.1, U1.34
RESET: C7.1, R2.2, TP6.1, U1.17
SPI_CS: PAD3.1, U1.32
SPI_MISO: PAD5.1, U1.30
SPI_MOSI: PAD6.1, U1.31
SPI_SCK: PAD4.1, U1.33
USB_DM: TP3.1, U1.2
USB_DP: TP4.1, U1.3
VBAT: BATT+.1, C5.1, U2.1, U2.3

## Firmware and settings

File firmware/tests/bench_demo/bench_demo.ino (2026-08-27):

// ============================================================================
//  OPEN VIBRATION NODE  -  bench acquisition demo
//
//  Streams live acceleration statistics from an IIS3DWB running at its full
//  26.667 kHz output data rate. Prints a self-check on start-up, then one row
//  per measurement block: per-axis mean (tilt / gravity), broadband RMS
//  (vibration), peak hold and die temperature.
//
//  Hardware : IIS3DWB on the sensor board, RAK3112 (ESP32-S3) as host MCU
//  Wiring   : SCK=13  MISO=10  MOSI=11  CS=12   (SPI mode 0)
//  Serial   : 115200 baud
// ============================================================================
#include <SPI.h>

const int SCK_PIN  = 13;
const int MISO_PIN = 10;
const int MOSI_PIN = 11;
const int CS_PIN   = 12;

// IIS3DWB registers (datasheet DS12569)
#define REG_WHO_AM_I   0x0F
#define REG_CTRL1_XL   0x10
#define REG_CTRL3_C    0x12
#define REG_STATUS     0x1E
#define REG_OUT_TEMP_L 0x20
#define REG_OUTX_L_A   0x28

#define WHO_AM_I_EXPECTED 0x7B

const float MG_PER_LSB = 0.244f;   // +/-8 g full scale
const int   N_SAMPLES  = 256;      // samples per reported block
const int   PEAK_HOLD_BLOCKS = 20; // peak resets roughly every 5 s

SPISettings spiCfg(8000000, MSBFIRST, SPI_MODE0);

uint8_t readReg(uint8_t reg) {
  SPI.beginTransaction(spiCfg);
  digitalWrite(CS_PIN, LOW);
  SPI.transfer(reg | 0x80);
  uint8_t v = SPI.transfer(0x00);
  digitalWrite(CS_PIN, HIGH);
  SPI.endTransaction();
  return v;
}

void writeReg(uint8_t reg, uint8_t val) {
  SPI.beginTransaction(spiCfg);
  digitalWrite(CS_PIN, LOW);
  SPI.transfer(reg & 0x7F);
  SPI.transfer(val);
  digitalWrite(CS_PIN, HIGH);
  SPI.endTransaction();
}

void readBytes(uint8_t reg, uint8_t *buf, int n) {
  SPI.beginTransaction(spiCfg);
  digitalWrite(CS_PIN, LOW);
  SPI.transfer(reg | 0x80);
  for (int i = 0; i < n; i++) buf[i] = SPI.transfer(0x00);
  digitalWrite(CS_PIN, HIGH);
  SPI.endTransaction();
}

// Collect one block; returns per-axis mean and RMS about the mean, in mg.
void acquireBlock(float *mean, float *rms) {
  double s[3] = {0, 0, 0}, q[3] = {0, 0, 0};
  uint8_t raw[6];
  for (int i = 0; i < N_SAMPLES; i++) {
    while ((readReg(REG_STATUS) & 0x01) == 0) { }
    readBytes(REG_OUTX_L_A, raw, 6);
    for (int a = 0; a < 3; a++) {
      int16_t v = (int16_t)(raw[a * 2] | (raw[a * 2 + 1] << 8));
      s[a] += v;
      q[a] += (double)v * v;
    }
  }
  for (int a = 0; a < 3; a++) {
    double m = s[a] / N_SAMPLES;
    double var = q[a] / N_SAMPLES - m * m;
    mean[a] = m * MG_PER_LSB;
    rms[a]  = sqrt(var > 0 ? var : 0) * MG_PER_LSB;
  }
}

float readTemperature() {
  uint8_t t[2];
  readBytes(REG_OUT_TEMP_L, t, 2);
  int16_t raw = (int16_t)(t[0] | (t[1] << 8));
  return 25.0f + raw / 256.0f;
}

void setup() {
  Serial.begin(115200);
  delay(2500);

  pinMode(CS_PIN, OUTPUT);
  digitalWrite(CS_PIN, HIGH);
  SPI.begin(SCK_PIN, MISO_PIN, MOSI_PIN, CS_PIN);

  Serial.println();
  Serial.println("================================================================");
  Serial.println("  OPEN VIBRATION NODE   -   bench acquisition demo");
  Serial.println("  github.com/ammygo/open-vibration-node");
  Serial.println("================================================================");

  // --- sensor identification ---
  uint8_t id = 0;
  for (int i = 0; i < 5 && id != WHO_AM_I_EXPECTED; i++) {
    id = readReg(REG_WHO_AM_I);
    if (id != WHO_AM_I_EXPECTED) delay(100);
  }
  Serial.print("  Sensor ID (WHO_AM_I) : 0x");
  Serial.print(id, HEX);
  Serial.println(id == WHO_AM_I_EXPECTED ? "   [ OK ]   IIS3DWB detected"
                                         : "   [FAIL]   expected 0x7B");
  if (id != WHO_AM_I_EXPECTED) {
    while (true) {
      Serial.println("  Sensor not responding - check wiring and power.");
      delay(3000);
    }
  }

  // --- configure ---
  writeReg(REG_CTRL3_C, 0x01);          // software reset
  delay(20);
  writeReg(REG_CTRL3_C, 0x44);          // block data update + auto increment
  // XL_EN[2:0] = 101 (bits 7:5) is the ONLY valid ODR: 26.667 kHz.
  // FS_XL[1:0] = 11 (bits 3:2) selects +/-8 g.  -> 0xAC
  writeReg(REG_CTRL1_XL, 0xAC);
  delay(50);

  uint8_t ctrl1 = readReg(REG_CTRL1_XL);
  Serial.print("  CTRL1_XL read-back   : 0x");
  Serial.print(ctrl1, HEX);
  Serial.println(ctrl1 == 0xAC ? "   [ OK ]   26.667 kHz ODR, +/-8 g"
                               : "   [FAIL]   configuration not accepted");
  Serial.println("  Full scale           : +/-8 g   (0.244 mg/LSB)");
  Serial.println("  SPI                  : mode 0, 8 MHz");
  Serial.print  ("  Block size           : ");
  Serial.print(N_SAMPLES);
  Serial.println(" samples");

  // --- 1 g reference check (also times the polled readout rate) ---
  float mean[3], rms[3];
  uint32_t t0 = micros();
  acquireBlock(mean, rms);
  uint32_t dt = micros() - t0;
  Serial.print("  Host readout rate    : ");
  Serial.print(N_SAMPLES * 1e6f / dt / 1000.0f, 1);
  Serial.println(" kS/s polled (sensor ODR 26.667 kHz)");
  float total = sqrt(mean[0] * mean[0] + mean[1] * mean[1] + mean[2] * mean[2]);
  Serial.print("  Gravity vector       : ");
  Serial.print(total, 0);
  Serial.print(" mg");
  Serial.println((total > 900 && total < 1100) ? "   [ OK ]   within 10% of 1 g"
                                               : "   [ ?? ]   board in motion?");
  float noise = sqrt(rms[0] * rms[0] + rms[1] * rms[1] + rms[2] * rms[2]);
  Serial.print("  Noise floor at rest  : ");
  Serial.print(noise, 1);
  Serial.println(" mg RMS");

  Serial.println("----------------------------------------------------------------");
  Serial.println("  Tap the surface to see the vibration level respond.");
  Serial.println("----------------------------------------------------------------");
  Serial.println("   time     X mg      Y mg      Z mg    RMS mg   peak    T C");
  Serial.println("----------------------------------------------------------------");
}

void loop() {
  static float peak = 0;
  static int   blocks = 0;

  float mean[3], rms[3];
  acquireBlock(mean, rms);
  float vib = sqrt(rms[0] * rms[0] + rms[1] * rms[1] + rms[2] * rms[2]);

  if (++blocks >= PEAK_HOLD_BLOCKS) { peak = 0; blocks = 0; }
  if (vib > peak) peak = vib;

  char line[160];
  snprintf(line, sizeof(line),
           "  %5.1fs  %+8.1f  %+8.1f  %+8.1f  %8.1f %6.1f  %5.1f  ",
           millis() / 1000.0f, mean[0], mean[1], mean[2],
           vib, peak, readTemperature());
  Serial.print(line);

  int bars = (int)(vib / 20.0f);        // one mark per 20 mg
  if (bars > 40) bars = 40;
  for (int i = 0; i < bars; i++) Serial.print('#');
  Serial.println();

  delay(200);
}

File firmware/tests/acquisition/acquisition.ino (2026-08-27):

// ============================================================
// IIS3DWB PILNAS TESTAS - vibracija + temperatura
// Plokste: RAK3112 (ESP32-S3) virsutine + IIS3DWB apatine (V5)
// Kojos tos pacios kaip WHO_AM_I teste: SCK=13 MISO=10 MOSI=11 CS=12
// Serial Monitor: 115200 baud
// ============================================================
#include <SPI.h>

const int SCK_PIN  = 13;
const int MISO_PIN = 10;
const int MOSI_PIN = 11;
const int CS_PIN   = 12;

// IIS3DWB registrai (DS12569)
#define REG_WHO_AM_I   0x0F   // turi grazinti 0x7B
#define REG_CTRL1_XL   0x10   // ijungimas + skale
#define REG_CTRL3_C    0x12   // BDU, IF_INC, SW_RESET
#define REG_STATUS     0x1E   // bit0 = nauji XYZ duomenys
#define REG_OUT_TEMP_L 0x20   // temperatura 16 bit
#define REG_OUTX_L_A   0x28   // X,Y,Z po 16 bit (6 baitai)

const float MG_PER_LSB = 0.244f;   // +-8g skale: 0.244 mg/LSB
const int   N_SAMPLES  = 256;      // kiek meginiu vienam matavimui

SPISettings spiCfg(2000000, MSBFIRST, SPI_MODE0);  // IIS3DWB = tik Mode 0

// ---------- zemo lygio SPI ----------
uint8_t readReg(uint8_t reg) {
  SPI.beginTransaction(spiCfg);
  digitalWrite(CS_PIN, LOW);
  SPI.transfer(reg | 0x80);          // MSB=1 -> skaitymas
  uint8_t v = SPI.transfer(0x00);
  digitalWrite(CS_PIN, HIGH);
  SPI.endTransaction();
  return v;
}

void writeReg(uint8_t reg, uint8_t val) {
  SPI.beginTransaction(spiCfg);
  digitalWrite(CS_PIN, LOW);
  SPI.transfer(reg & 0x7F);          // MSB=0 -> rasymas
  SPI.transfer(val);
  digitalWrite(CS_PIN, HIGH);
  SPI.endTransaction();
}

void readBytes(uint8_t reg, uint8_t *buf, int n) {
  SPI.beginTransaction(spiCfg);
  digitalWrite(CS_PIN, LOW);
  SPI.transfer(reg | 0x80);
  for (int i = 0; i < n; i++) buf[i] = SPI.transfer(0x00);
  digitalWrite(CS_PIN, HIGH);
  SPI.endTransaction();
}

// ---------- paleidimas ----------
void setup() {
  Serial.begin(115200);
  delay(2000);
  Serial.println();
  Serial.println("=== IIS3DWB PILNAS TESTAS ===");

  pinMode(CS_PIN, OUTPUT);
  digitalWrite(CS_PIN, HIGH);
  SPI.begin(SCK_PIN, MISO_PIN, MOSI_PIN, CS_PIN);

  // 1) WHO_AM_I patikra (5 bandymai)
  uint8_t id = 0;
  for (int i = 0; i < 5; i++) {
    id = readReg(REG_WHO_AM_I);
    if (id == 0x7B) break;
    delay(100);
  }
  Serial.print("WHO_AM_I: 0x");
  Serial.println(id, HEX);
  if (id != 0x7B) {
    while (true) {
      Serial.println("KLAIDA: jutiklis neatsako (turi buti 0x7B). Patikrink laidus.");
      delay(2000);
    }
  }
  Serial.println("Jutiklis rastas: IIS3DWB (0x7B) - OK");

  // 2) Programinis resetas ir konfiguracija
  writeReg(REG_CTRL3_C, 0x01);       // SW_RESET
  delay(20);
  writeReg(REG_CTRL3_C, 0x44);       // BDU=1 (nesumaisyti baitu), IF_INC=1
  writeReg(REG_CTRL1_XL, 0xAC);      // XL_EN[2:0]=101 (bitai 7:5) = 26.7 kHz; FS=+-8g (bitai 3:2)
                                     // PATAISA 2026-08-28: buvo 0x2C - nedokumentuota kombinacija,
                                     // jutiklis realiai dirbo ~105 Hz, ne 26.7 kHz
  delay(10);
  Serial.println("Jutiklis ijungtas: 26.7 kHz, +-8g");
  Serial.println();
  Serial.println("Gulint ramiai Z turi rodyti apie +-1000 mg (gravitacija).");
  Serial.println("Pabelsk pirstu i stala - RMS ir juosta soktels.");
  Serial.println("------------------------------------------------------------");
}

// ---------- pagrindinis ciklas ----------
void loop() {
  // Surenkam N meginiu kuo greiciau (jutiklis duoda nauja megini kas 37.5 us)
  double sx = 0, sy = 0, sz = 0;         // sumos vidurkiui
  double qx = 0, qy = 0, qz = 0;         // kvadratu sumos RMS skaiciavimui
  uint8_t raw[6];

  for (int i = 0; i < N_SAMPLES; i++) {
    while ((readReg(REG_STATUS) & 0x01) == 0) { }   // laukiam naujo meginio
    readBytes(REG_OUTX_L_A, raw, 6);
    int16_t x = (int16_t)(raw[0] | (raw[1] << 8));
    int16_t y = (int16_t)(raw[2] | (raw[3] << 8));
    int16_t z = (int16_t)(raw[4] | (raw[5] << 8));
    sx += x;  sy += y;  sz += z;
    qx += (double)x * x;  qy += (double)y * y;  qz += (double)z * z;
  }

  // Vidurkiai (nuolatine dedamoji = pasvirimas/gravitacija), mg
  float mx = (sx / N_SAMPLES) * MG_PER_LSB;
  float my = (sy / N_SAMPLES) * MG_PER_LSB;
  float mz = (sz / N_SAMPLES) * MG_PER_LSB;

  // RMS aplink vidurki (kintama dedamoji = vibracija), mg
  float rx = sqrt(qx / N_SAMPLES - (sx / N_SAMPLES) * (sx / N_SAMPLES)) * MG_PER_LSB;
  float ry = sqrt(qy / N_SAMPLES - (sy / N_SAMPLES) * (sy / N_SAMPLES)) * MG_PER_LSB;
  float rz = sqrt(qz / N_SAMPLES - (sz / N_SAMPLES) * (sz / N_SAMPLES)) * MG_PER_LSB;
  float vib = sqrt(rx * rx + ry * ry + rz * rz);   // bendras vibracijos lygis

  // Temperatura: 25 C + raw/256
  uint8_t t[2];
  readBytes(REG_OUT_TEMP_L, t, 2);
  int16_t traw = (int16_t)(t[0] | (t[1] << 8));
  float tempC = 25.0f + traw / 256.0f;

  // Spausdinimas
  char line[160];
  snprintf(line, sizeof(line),
           "X:%+8.1f mg  Y:%+8.1f mg  Z:%+8.1f mg | vib RMS:%7.1f mg | T:%5.1f C | ",
           mx, my, mz, vib, tempC);
  Serial.print(line);

  // Vibracijos juosta: 1 bruksnys = 10 mg (max 50)
  int bars = (int)(vib / 10.0f);
  if (bars > 50) bars = 50;
  for (int i = 0; i < bars; i++) Serial.print('#');
  Serial.println();

  delay(250);
}

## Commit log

2026-08-24 Initial commit: project scope, licences and repository structure
    Open hardware LoRaWAN vibration sensing node for industrial condition
    monitoring: on-device FFT and envelope analysis, local-first operation,
    no mandatory cloud service.
2026-08-27 Correct hardware description, add bench tests and measurements
    - Fix component listing: IIS3DWB accelerometer and RAK3112 module (the
    earlier ADXL355/nRF52840 description was inaccurate)
    - Document why these parts were chosen: 6.3 kHz bandwidth is what makes
    bearing diagnostics possible; on-module radio for reproducibility
    - Describe the two-board architecture and inter-board signals
    - Add bench verification sketches and first characterisation results
    (noise floor ~1 mg RMS, gravity and impact response verified)
    [acquisition.ino, sensor_id.ino]
2026-08-27 Publish mounting pad design (v1, without sensor pocket)
    Threaded M6 pad that couples the sensor board to the machine surface.
    Parametric OpenSCAD source plus STEP and STL exports. Documents why a
    rigid threaded coupling is used instead of a magnet or adhesive, and
    records the known v1 limitation: no recess for the accelerometer package.
    [mounting_pad_v1.scad, mounting_pad_v1.step, mounting_pad_v1.stl]
2026-08-27 Publish handedness checker for bottom-mounted footprints
    A mirrored footprint on the bottom layer passes DRC and fabricator review
    yet makes assembly impossible; it cost three board revisions here. The
    script compares KiCad pad positions against the datasheet bottom view at
    all four rotations and fails if none match. Documents the underlying rule
    in plain language, with real output from the current board.
2026-08-27 Publish sensor housing model (v3, work in progress)
    Fusion 360 source with a STEP export so the design can be opened without
    a proprietary licence. Documents the constraints the housing has to
    satisfy: rigid sensor path, radio transparency, O-ring sealing, vented
    pressure equalisation. Also corrects the mounting pad pocket dimensions.
    [sensor_housing_v3.f3d, sensor_housing_v3.step]
2026-08-27 Publish production files and correct overstated claims
    Publish gerbers, BOM and pick-and-place data for both boards, so that
    'reproducible' describes what the repository actually offers rather than
    what it promises. Prices, suppliers and order references are excluded.
    Corrections after review:
    - Radio: the SX1262 path has not been brought up, so the status and the
    LoRaWAN references now say what is true — LoRa hardware, protocol still
    under evaluation
    - Power: the assembled boards use an AP2112K-3.3, not the TPS7A02 named
    earlier
    - Replace the categorical 'there is no open node' claim with a specific,
    first-person account of what existing projects do and where the gap is
    - Mark th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
    [bom.xlsx, pick-and-place.xlsx, sensor_bottom.kicad_pcb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]
2026-08-27 Fix roadmap contradiction and document KiCad/gerber differences
    The roadmap claimed the radio was validated while the status section
    correctly said it had not been brought up. Split into separate steps.
    Also record what the KiCad sources actually contain: the sensor board
    differs from the manufactured gerbers by ~0.1 mm on one CS track, and the
    radio board carries placement and netlist only — its routing exists in
    the gerbers alone. Without this, someone opening the radio board would
    reasonably conclude the file was broken.
    Mark the housing as published and note that current prototypes print in
    PLA, not the ASA/PC intended for field units.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
2026-08-27 Correct noise floor: sensor had been running at the wrong rate
    CTRL1_XL was written as 0x2C, an undocumented combination the part
    accepts while running at ~105 Hz instead of 26.667 kHz. The published
    ~1 mg RMS noise floor was correct for that bandwidth and impossible for
    the full one — 75 ug/sqrt(Hz) over 6.3 kHz puts the floor near 5.9 mg.
    Corrected value is 0xAC. Re-measured floor at full bandwidth is ~18 mg
    RMS on a bench, the excess over the datasheet figure being building
    vibration and harness microphonics rather than the sensor.
    Gravity, orientation, identification and settling results are unaffected.
    Documents how the error surfaced (block timing, then a diagnostic sketch)
    and add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
    [acquisition.ino, bench_demo.ino]
2026-08-27 Add photographs of the built hardware
    Eight images of the node as built: both boards with a scale reference,
    an exploded view of every part, the assembled node on its mounting pad,
    the opened housing, the bench setup and the self-check output.
    Device identifiers on the radio module and the energy-buffer capacitor
    markings are pixelated; nothing needed to rebuild the node is obscured.
2026-08-27 Add comparison section, payload spec draft, contributing guide and roadmap dates
    - Compare the four existing approaches honestly: commercial closed
    systems, consumer-MEMS open builds, wired piezo setups, and this node
    - Publish a draft uplink payload specification (19 of 24 bytes, versioned,
    with self-asserting configuration flags born from the ODR errata) as a
    basis for third-party decoders — explicitly marked draft, open questions listed
    - Add CONTRIBUTING.md focused on review and reproduction
    - Put indicative dates on the roadmap
2026-08-27 Payload spec: fix peak field overflow, amplitude reference, add FIFO requirement
    Review findings from bench-firmware fact-check:
    - Peak at 0.1 mg/uint16 clipped at 6553.5 mg, below the sensor's 8000 mg
    full scale — now 0.25 mg steps; the clipping flag again means true
    saturation rather than encoding overflow
    - Spectral amplitude re-referenced from 1 mg to 0.1 mg: unsigned dB re
    1 mg could not represent the 0.3–1 mg region where early bearing
    defects live (per-bin noise floor ≈ 0.27 mg at 13 Hz bins)
    - Battery field annotated: current boards have no sense divider
    - New section: spectral acquisition must use the sensor FIFO with burst
    reads — polled reads reach only 14–17 k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
2026-08-27 Protocol decided: LoRaWAN with a self-hosted ChirpStack server
    Replace the 'under evaluation' wording throughout. The reference gateway
    is a Raspberry Pi 5 with an SX1302 eight-channel concentrator running
    ChirpStack, so radio, network server and database all sit on hardware the
    operator owns.
    Also document the second data path: the module's 8 MB of PSRAM holds
    about 50 seconds of the full 26.667 kHz three-axis stream, retrievable
    over WiFi on demand. Routine monitoring stays a summary of a few dozen
    bytes; full detail is available when a trend warrants investigation.
2026-09-03 docs: September 2026 bench results — ISO 10816 velocity RMS, second erratum, payload status, roadmap
    - measurements.md: velocity RMS in the 10–1000 Hz band (FIFO, 8192-sample window,
    Butterworth chain) with the synthetic-signal validation table; Errata 2 — polled
    acquisition dropped ~40 % of samples before firmware v6
    - payload-spec.md: bench protocol status — sensor-health flag, reboot detection and the
    duty-cycle airtime budget (226 ms at SF7 → 3 s minimum cadence) already exercised
    - README: radio bring-up done (roadmap item 2), interim analysis path, raw capture over
    WiFi working on the bench
    - tools/vrms_filter_check.py: dependency-free script reproducing the validatio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
2026-09-03 docs: Errata 3 — bench cadence exceeded the duty-cycle limit; time-on-air formula
2026-09-04 docs: review fixes — health-flag polarity, LoRaWAN 1 % airtime budget, reboot wording, collector consistency
